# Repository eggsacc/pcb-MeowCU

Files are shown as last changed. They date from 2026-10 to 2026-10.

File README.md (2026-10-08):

<div align="center">

# MeowCU





4-layer **STM32F405RGT6 MeowCU** 🐱 (MCU) dev module with commonly used peripherals broken out for easy access, and a dedicated CAN transceiver. Also includes 2 user programmable buttons and mini OLED display.

>3D render - Front

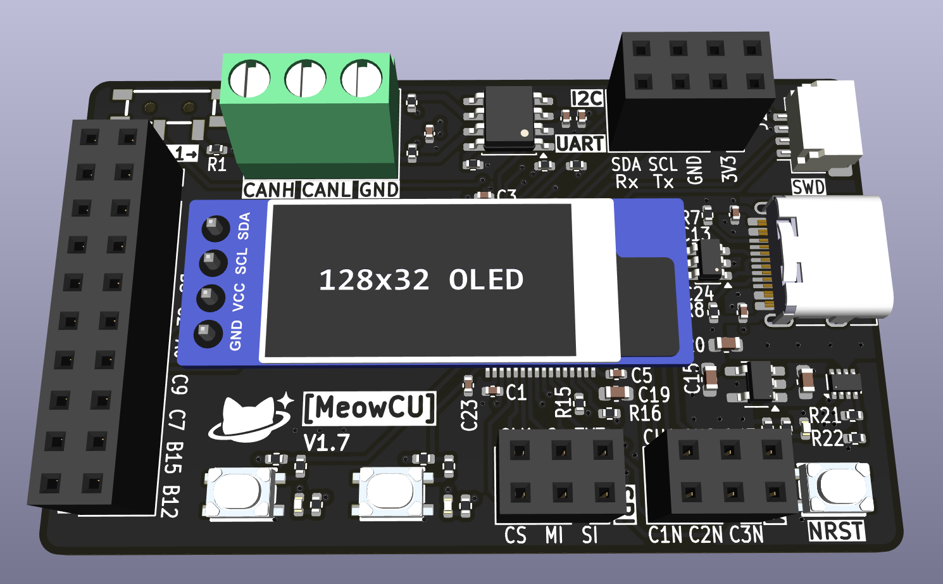
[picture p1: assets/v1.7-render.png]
STM32F4 dev module render


>Back

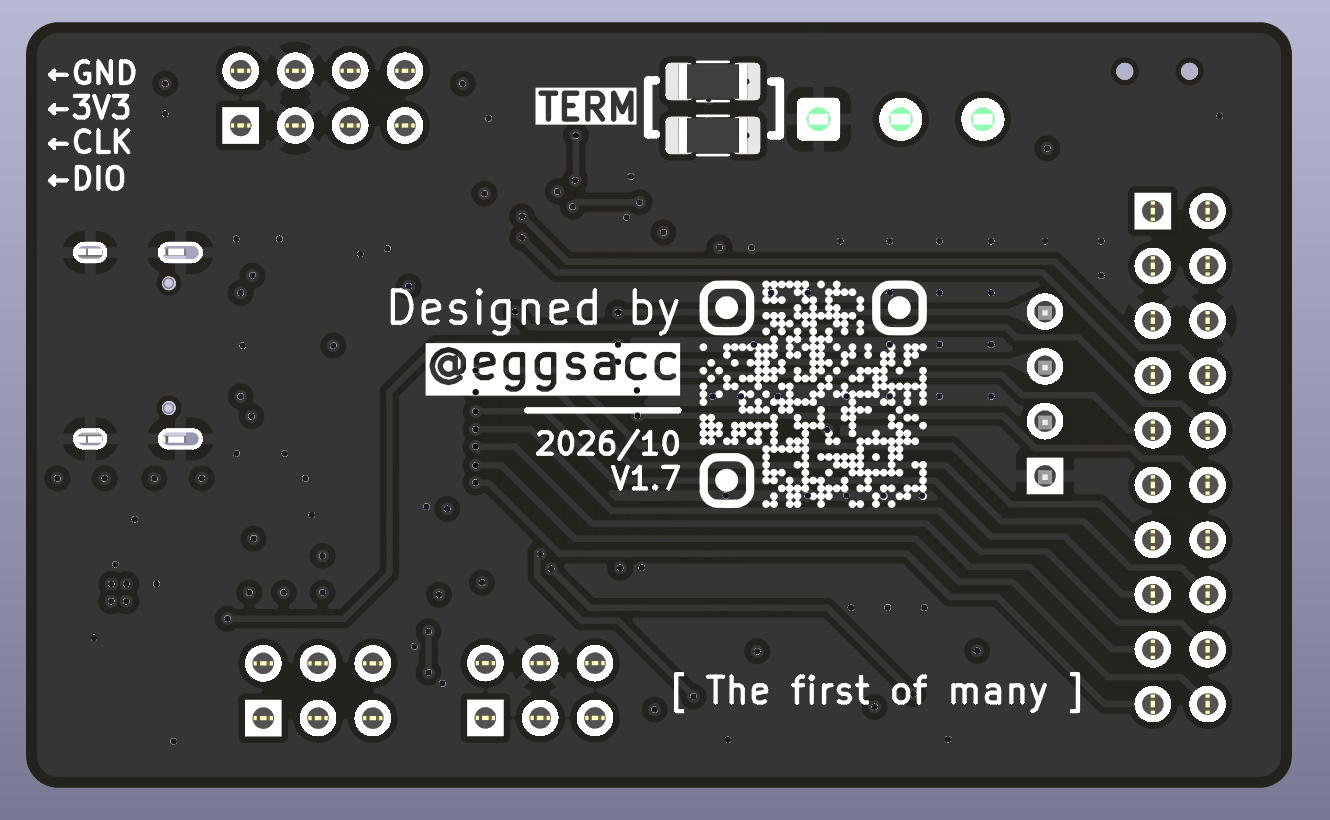
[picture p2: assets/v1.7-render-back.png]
STM32F4 dev module render


## Layout (all layers)
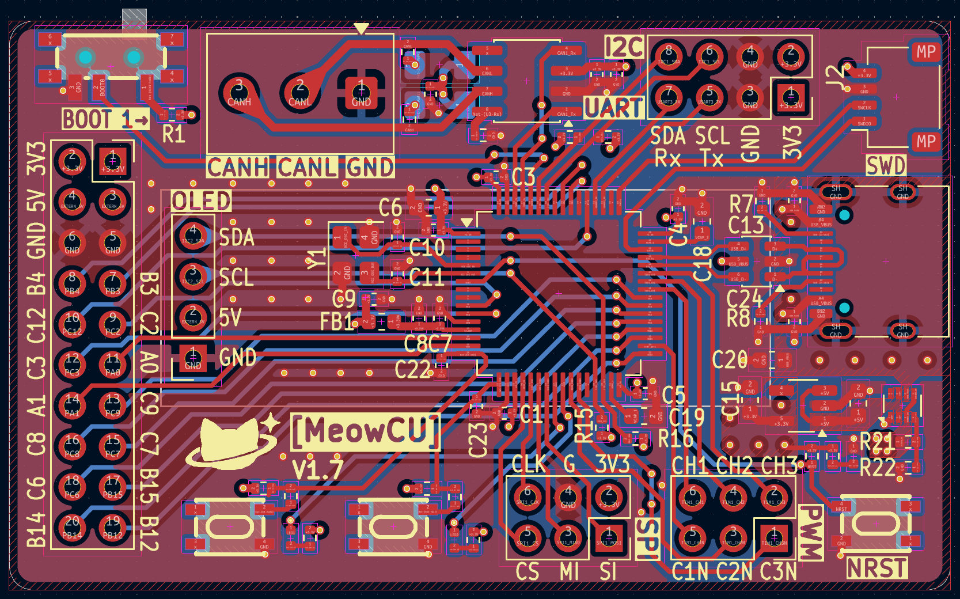
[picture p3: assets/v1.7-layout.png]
STM32CubeMX pin map

</div>

## MCU Pinout

<div align="center">
STM32CubeMX pin map

| Breakout / feature | Peripheral | Pin mapping |
|---|---|---|
| **UART header** | `USART3` | TX &rarr; `PC10`<br>RX &rarr; `PC11` |
| **SPI header** | `SPI1` | CS &rarr; `PA4`<br>SCK &rarr; `PA5`<br>MISO &rarr; `PA6`<br>MOSI &rarr; `PA7` |
| **I2C header** | `I2C1` | SCL &rarr; `PB6`<br>SDA &rarr; `PB7` |
| **CAN screw terminal** | `CAN1` (SN65HVD230) | TX &rarr; `PB9`<br>RX &rarr; `PB8` |
| **USB-C** | `USB_OTG_FS` | D&minus; &rarr; `PA11`<br>D+ &rarr; `PA12` |
| **SWD header** | `SYS` | SWDIO &rarr; `PA13`<br>SWCLK &rarr; `PA14` |
| **3-phase PWM header** | `TIM1` | <table><tbody><tr><td align="right">CH1 &rarr;</td><td><code>PA8</code></td><td align="right">&emsp;C1N &rarr;</td><td><code>PB13</code></td></tr><tr><td align="right">CH2 &rarr;</td><td><code>PA9</code></td><td align="right">&emsp;C2N &rarr;</td><td><code>PB0</code></td></tr><tr><td align="right">CH3 &rarr;</td><td><code>PA10</code></td><td align="right">&emsp;C3N &rarr;</td><td><code>PB1</code></td></tr></tbody></table> |
| **OLED** (on-board) | `I2C2` | SCL &rarr; `PB10`<br>SDA &rarr; `PB11` |
| **Utility buttons** (on-board) | `GPIO` / `EXTI` | L button &rarr; `PA2`<br>R button &rarr; `PA3` |
| **Crystal** (25MHz) | `RCC` HSE | OSC_IN &rarr; `PH0`<br>OSC_OUT &rarr; `PH1` |
| **GPIO header** (2&times;10) | free GPIO | <table><tbody><tr><td align="right">1 &rarr;</td><td><code>3.3V</code></td><td align="right">&emsp;2 &rarr;</td><td><code>3.3V</code></td></tr><tr><td align="right">3 &rarr;</td><td><code>5V</code></td><td align="right">&emsp;4 &rarr;</td><td><code>5V</code></td></tr><tr><td align="right">5 &rarr;</td><td><code>GND</code></td><td align="right">&emsp;6 &rarr;</td><td><code>GND</code></td></tr><tr><td align="right">7 &rarr;</td><td><code>PB4</code></td><td align="right">&emsp;8 &rarr;</td><td><code>PB3</code></td></tr><tr><td align="right">9 &rarr;</td><td><code>PC12</code></td><td align="right">&emsp;10 &rarr;</td><td><code>PC2</code></td></tr><tr><td align="right">11 &rarr;</td><td><code>PC3</code></td><td align="right">&emsp;12 &rarr;</td><td><code>PA0</code></td></tr><tr><td align="right">13 &rarr;</td><td><code>PA1</code></td><td align="right">&emsp;14 &rarr;</td><td><code>PC9</code></td></tr><tr><td align="right">15 &rarr;</td><td><code>PC8</code></td><td align="right">&emsp;16 &rarr;</td><td><code>PC7</code></td></tr><tr><td align="right">17 &rarr;</td><td><code>PC6</code></td><td align="right">&emsp;18 &rarr;</td><td><code>PB15</code></td></tr><tr><td align="right">19 &rarr;</td><td><code>PB14</code></td><td align="right">&emsp;20 &rarr;</td><td><code>PB12</code></td></tr></tbody></table> |

**Buttons are active-low to GND (3V3 pull-up).*
</div>

## Power mux

The external 5V pin and USB `vbus` are separate rails; a power mux IC (TPS2116) automatically switches to the external 5V rail when connected.

---

<div align="center">
Designed by <b>@eggsacc</b> · MeowCU V1.6<br>
Updated 09/10/2026
</div>

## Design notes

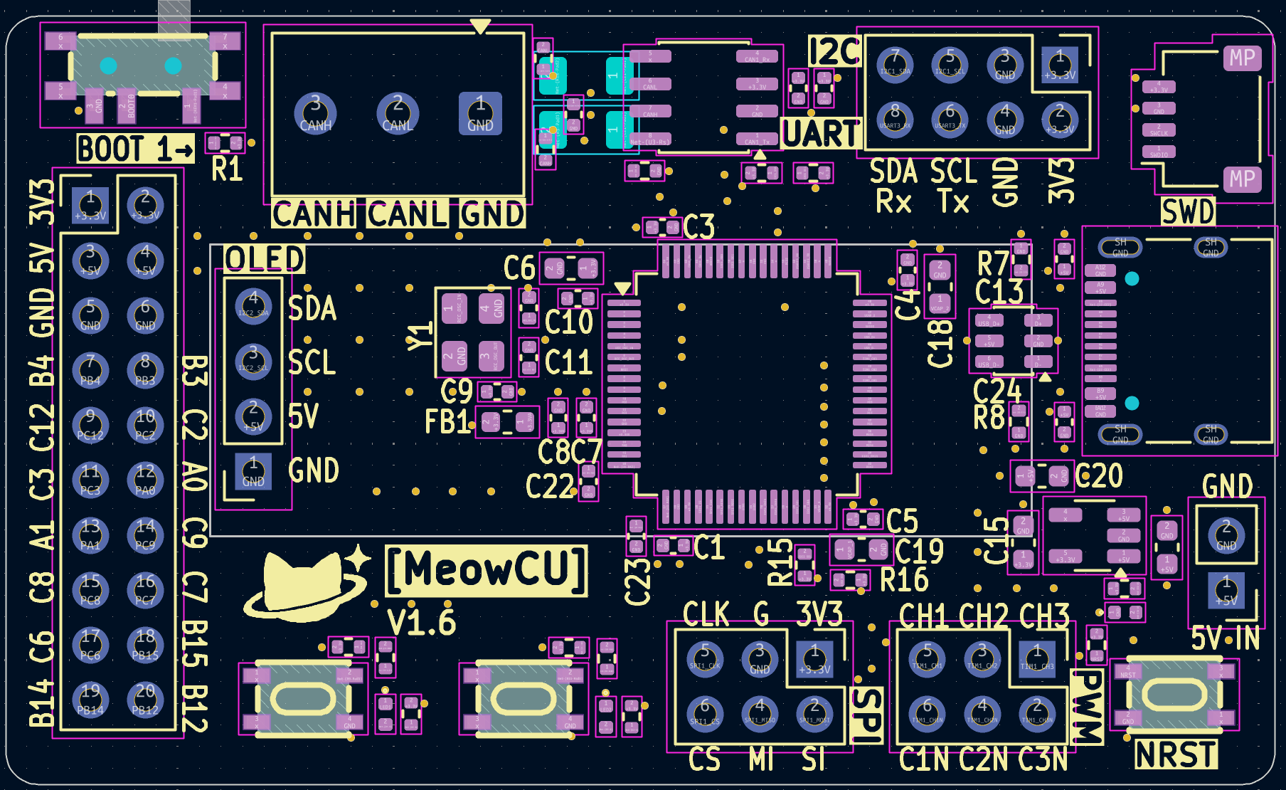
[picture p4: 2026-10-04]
assets/silkscreen-v1.6.png

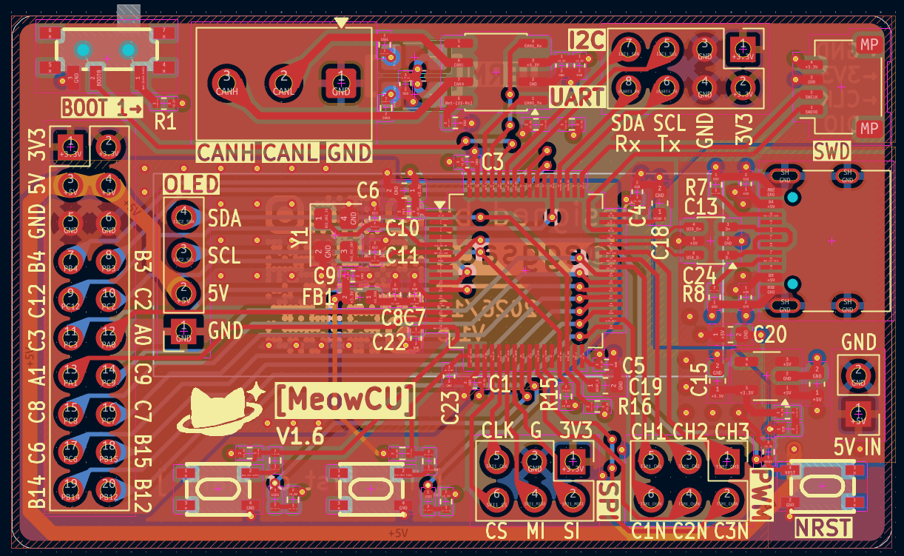
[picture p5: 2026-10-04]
assets/all-layers.png

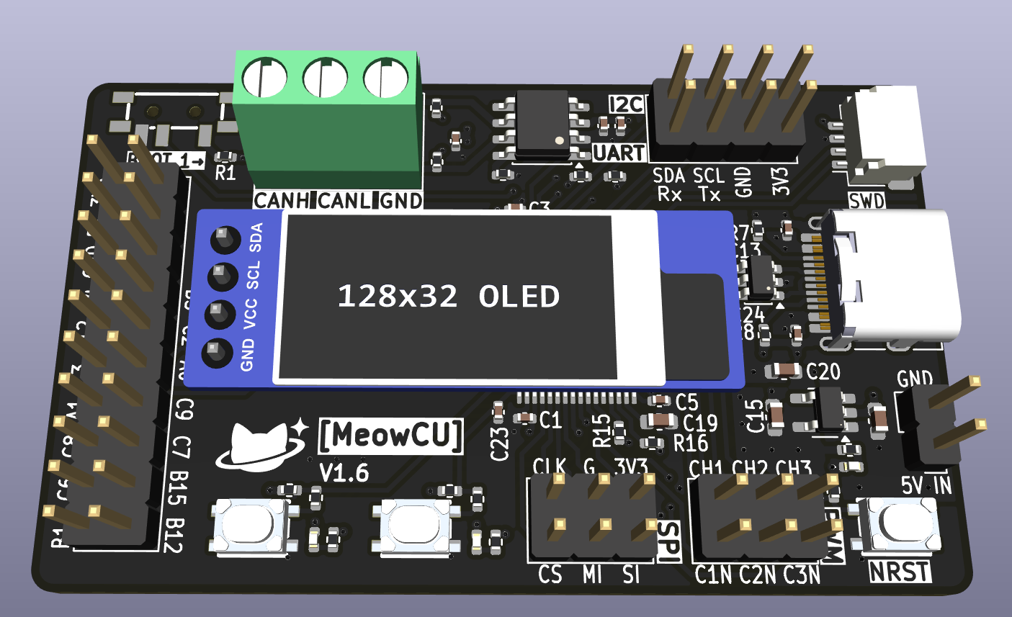
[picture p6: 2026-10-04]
assets/meowcu-v1.6-render.png

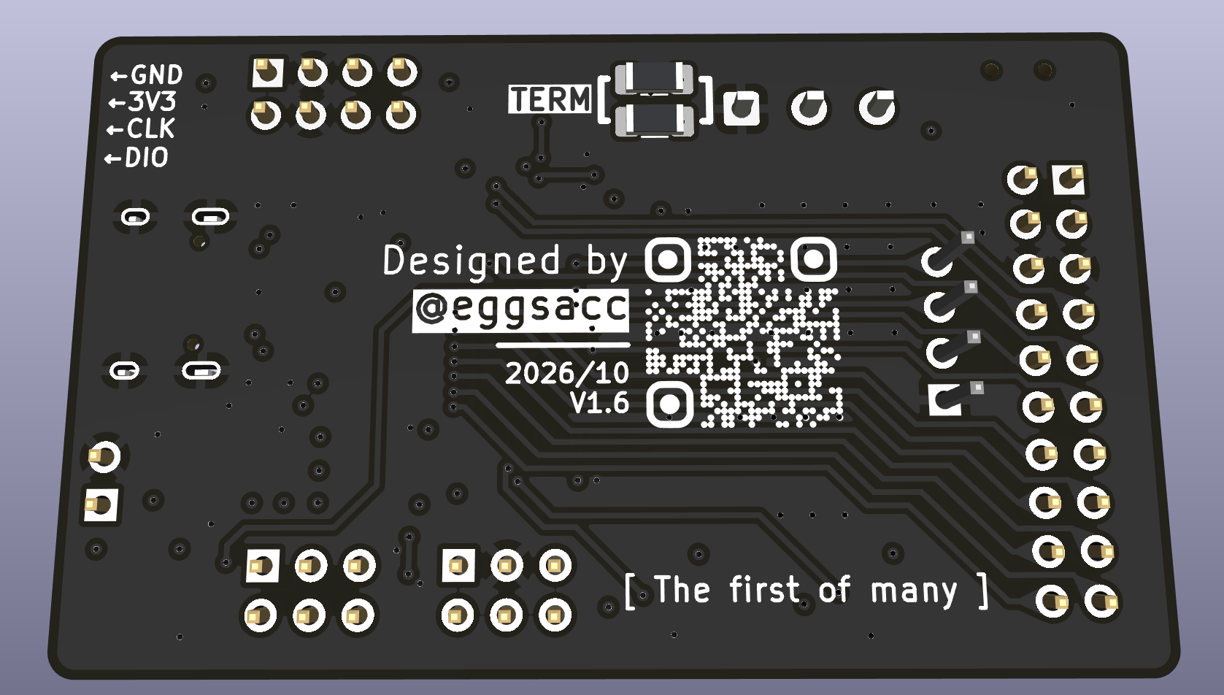
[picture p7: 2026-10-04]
assets/meowcu-v1.6-back-render.png

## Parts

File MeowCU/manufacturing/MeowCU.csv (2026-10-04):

Reference | Qty | Value | Footprint | Purhased | Qty | Link
C1,C2,C3,C4,C5,C13,C16,C22,C23,C24 | 10 | 100n | Capacitor_SMD:C_0402_1005Metric | TRUE | 100 | 0402??????? 22pF33pF47pF100pF2.2nF4.7nF100nF1uF10uF-???
C6 | 1 | 10u | Capacitor_SMD:C_0603_1608Metric | TRUE | 100 | 0603??????? 22pF33pF47pF100pF2.2nF4.7nF100nF1uF10uF-???
C7,C21 | 2 | 10n | Capacitor_SMD:C_0402_1005Metric | TRUE | 100 | 0402??????? 22pF33pF47pF100pF2.2nF4.7nF100nF1uF10uF-???
C8,C9,C17 | 3 | 1u | Capacitor_SMD:C_0402_1005Metric | TRUE | 100 | 0402??????? 22pF33pF47pF100pF2.2nF4.7nF100nF1uF10uF-???
C10,C11 | 2 | 14p | Capacitor_SMD:C_0402_1005Metric | TRUE | 100 | 0402??????? 22pF33pF47pF100pF2.2nF4.7nF100nF1uF10uF-???
C14,C15 | 2 | 1u | Capacitor_SMD:C_0603_1608Metric | TRUE | 100 | 0603??????? 22pF33pF47pF100pF2.2nF4.7nF100nF1uF10uF-???
C18,C19 | 2 | 2u2 | Capacitor_SMD:C_0603_1608Metric | TRUE | 100 | 0603??????? 22pF33pF47pF100pF2.2nF4.7nF100nF1uF10uF-???
C20 | 1 | 4u7 | Capacitor_SMD:C_0603_1608Metric | TRUE | 100 | 0603??????? 22pF33pF47pF100pF2.2nF4.7nF100nF1uF10uF-???
D1 | 1 | GREEN | LED_SMD:LED_0402_1005Metric | TRUE | 10 | ??LED 0402 0603 0805 1206??????? ?????????-tmall.com??
FB1 | 1 | 120R | Inductor_SMD:L_0603_1608Metric | TRUE | 100 | 0603?????????30R60R100R120R150R220R300R600R1K2K2.5K-???
J1 | 1 | SW | Connector_JST:JST_SH_SM04B-SRSS-TB_1x04-1MP_P1.00mm_Horizontal | TRUE | 10 | ???SH1.0??JSTSH ???1.0mm????/??/???????-???
J3 | 1 | I2C1 | Connector_PinHeader_2.54mm:PinHeader_1x04_P2.54mm_Vertical | TRUE | 0
J4 | 1 | SPI1 | Connector_PinHeader_2.54mm:PinHeader_2x03_P2.54mm_Vertical | TRUE | 0 | ?/??? ??2.54MM 1*2p/3p/4p/8P/16p/20p?? LCD1602/12864-tmall.com??
J5 | 1 | 5V_IN | Connector_PinHeader_2.54mm:PinHeader_1x02_P2.54mm_Vertical | TRUE | 0
J6 | 1 | OLED | addons:OLED header | TRUE | 0
J7 | 1 | USB_C_Receptacle_USB2.0_16P | Connector_USB:USB_C_Receptacle_G-Switch_GT-USB-7010ASV | TRUE | 0 | USB Type-C 16P?????????????????USB???-???
J8 | 1 | USART3 | Connector_PinHeader_2.54mm:PinHeader_1x04_P2.54mm_Vertical | TRUE | 0
J9 | 1 | PWM | Connector_PinHeader_2.54mm:PinHeader_2x03_P2.54mm_Vertical | TRUE | 0
J10 | 1 | Screw_Terminal_01x03 | TerminalBlock_Phoenix:TerminalBlock_Phoenix_MKDS-1-3-3.81_1x03_P3.81mm_Horizontal | TRUE | 0 | KF128/126????2P???2.54/3.81/5.08MM??5.0?????3P-tmall.com??
J11 | 1 | Conn_02x10_Odd_Even | Connector_PinHeader_2.54mm:PinHeader_2x10_P2.54mm_Vertical | TRUE | 0
R1,R3,R10,R12 | 4 | 10k | Resistor_SMD:R_0402_1005Metric | TRUE | 0 | 0402?????? ??1% 10R1K1.2K2.2K3.3K4.7K5.1K10K100K1M?-???
R2 | 1 | 330 | Resistor_SMD:R_0402_1005Metric | TRUE | 0 | 0402?????? ??1% 10R1K1.2K2.2K3.3K4.7K5.1K10K100K1M?-???
R4,R5 | 2 | 60 | Resistor_SMD:R_0402_1005Metric | TRUE | 0 | 0402?????? ??1% 10R1K1.2K2.2K3.3K4.7K5.1K10K100K1M?-???
R6 | 1 | 0 | Resistor_SMD:R_0603_1608Metric | TRUE | 0 | 0402 0603 0805 1206????1%5% 1R10R100R1K 4.7K10K 47K 100K-???
R7,R8 | 2 | 5k1 | Resistor_SMD:R_0402_1005Metric | TRUE | 0 | 0402?????? ??1% 10R1K1.2K2.2K3.3K4.7K5.1K10K100K1M?-???
R9,R11 | 2 | 100 | Resistor_SMD:R_0402_1005Metric | TRUE | 0 | 0402?????? ??1% 10R1K1.2K2.2K3.3K4.7K5.1K10K100K1M?-???
SW1 | 1 | SW_SPST | Button_Switch_SMD:SW_DIP_SPSTx01_Slide_6.7x4.1mm_W6.73mm_P2.54mm_LowProfile_JPin | TRUE | 10 | ??????/??1/2/3/4/5/6/7/8/9/10/12p??1.27/2.54mm??-???
SW5,SW6 | 2 | BTN_UTIL | addons:SW-SMD_4P-L4.2-W3.4-P2.15-LS5.2 | TRUE | 0 | ????4???2??????????????????????-tmall.com??
SW7 | 1 | BTN | addons:SW-SMD_4P-L4.2-W3.4-P2.15-LS5.2 | TRUE | 40 | ????4???2??????????????????????-tmall.com??
U1 | 1 | STM32F405RGT6 | Package_QFP:LQFP-64_10x10mm_P0.5mm | TRUE | 2 | ???? STM32F405RGT6 STM32F405VGT6 405ZGT6 405OEY6TR VGT7-tmall.com??
U2 | 1 | USBLC6-2SC6 | Package_TO_SOT_SMD:SOT-23-6 | TRUE | 20 | USBLC6-2SC6 USB2.0??ESD????? ???? ??UL26 SOT-23-tmall.com??
U3 | 1 | SN65HVD230 | Package_SO:SOIC-8_3.9x4.9mm_P1.27mm | TRUE | 5 | ???? ?? SN65HVD230DR SOP-8 CAN????? ??-???
U4 | 1 | AP2112K-3.3 | Package_TO_SOT_SMD:SOT-23-5_HandSoldering | TRUE | 10 | AP2112K-3.3TRG1 1.2V 1.8V 2.5V ??G3M LDO????? SOT23-5-???
Y1 | 1 | 25MHz | Crystal:Crystal_SMD_3225-4Pin_3.2x2.5mm | TRUE | 10 | 3225_4P???????? 8/12/13.56/16/20/24/25/26/32/40MHz-???
 |  |  | Request from seller values
 | ??
 | 1 | 100nF, 16V, X7R | 0402
 | 2 | 10nF, 50V, X7R | 0402
 | 3 | 1uF, 25V, X5R, 10% | 0402
 | 4 | 13pF, 50V, C0G | 0402
 | 5 | 1uF, 16V, X7R, 10% | 0603
 | 6 | 2.2uF, 16V, X7R, 10% | 0603
 | 7 | 4.7uF, 16V, X5R, 10% | 0603
 | 8 | 10uF, 10V, X5R, 10% | 0603
 | ??
 | 1 | 10k | 0402
 | 2 | 330 | 0402
 | 3 | 60 | 0402
 | 4 | 5.1K | 0402
 | 5 | 100 | 0403
 | 6 | 0 | 0603

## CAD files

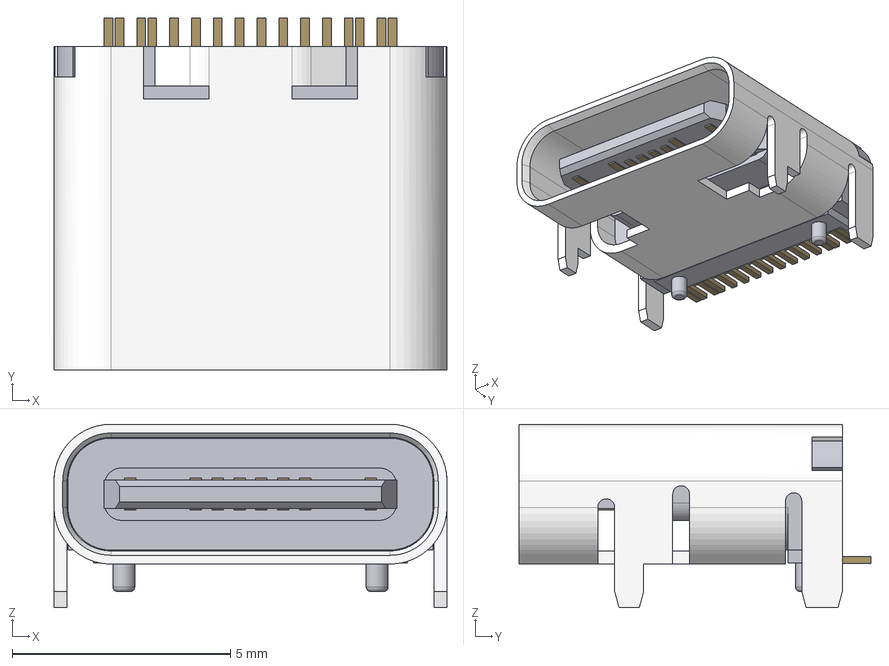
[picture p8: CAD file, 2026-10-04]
MeowCU/3d-models/usb-c_16pins_vertical.step
9.00 x 8.05 x 4.20 mm
tongue
shield
contact_001
contact_002
contact_003
contact_004
contact_court_001
contact_court_002
contact_court_003
contact_court_004
contact_005
contact_006
contact_007
contact_008
contact_court_005
contact_court_006
contact_court_007
contact_court_008
pin_001
pin_002
pin_003
pin_004
pin_005
pin_006
pin_007
pin_008
pin_009
pin_010
pin_011
pin_012
pin_013
pin_014
pin_015
pin_016

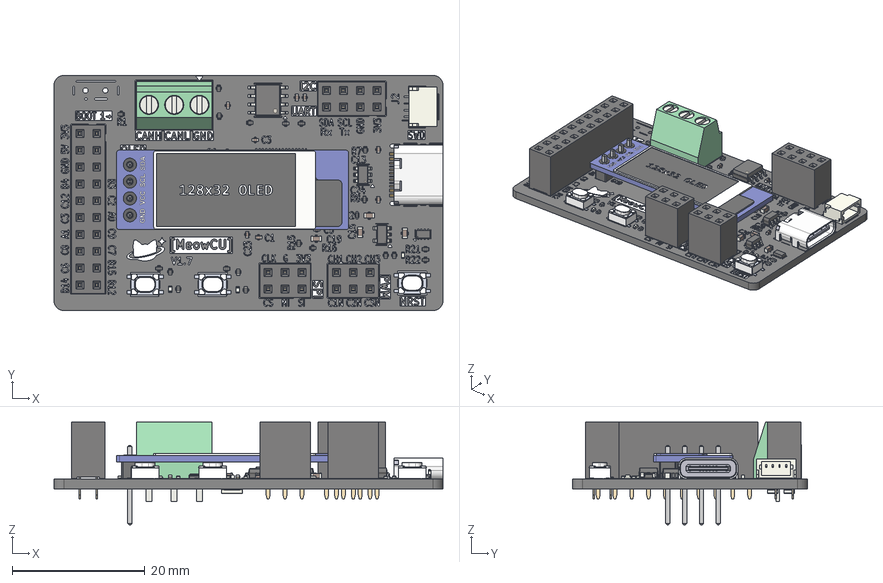
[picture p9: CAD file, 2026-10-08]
MeowCU/MeowCU.step
58.7 x 35.5 x 15.5 mm
C_0402_1005Metric x 17
R_0402_1005Metric x 20
SOT-23-5
LED_0402_1005Metric x 3
C_0603_1608Metric x 6
L_0603_1608Metric
JST_SH_SM04B-SRSS-TB_1x04-1MP_P1.00mm_Horizontal
PinSocket_2x03_P2.54mm_Vertical x 2
Crystal_SMD_3225-4Pin_3.2x2.5mm
PinSocket_2x04_P2.54mm_Vertical
TerminalBlock_Phoenix_MKDS-1-3-3.81_1x03_P3.81mm_Horizontal
sw3x4 x 3
sw3x4_cap x 3
sw3x4_cover x 3
sw3x4_hold x 3
sw3x4_pin x 6
¾µвsw3x4_hold x 6
¾µв¾µвsw3x4_hold x 3
SOT-23-6
PinSocket_2x10_P2.54mm_Vertical
SOIC-8_3.9x4.9mm_P1.27mm
SOT-583-8
tongue
shield
contact_001
contact_002
contact_003
contact_004
contact_court_001
contact_court_002
contact_court_003
contact_court_004
contact_005
contact_006
contact_007
contact_008
contact_court_005
contact_court_006
contact_court_007
contact_court_008
pin_001
pin_002
pin_003
pin_004
pin_005
pin_006
pin_007
pin_008
pin_009
pin_010
pin_011
pin_012
pin_013
pin_014
pin_015
pin_016
LQFP-64_10x10mm_P0.5mm
R_1206_3216Metric x 2
MeowCU_silkscreen x 2
MeowCU_PCB

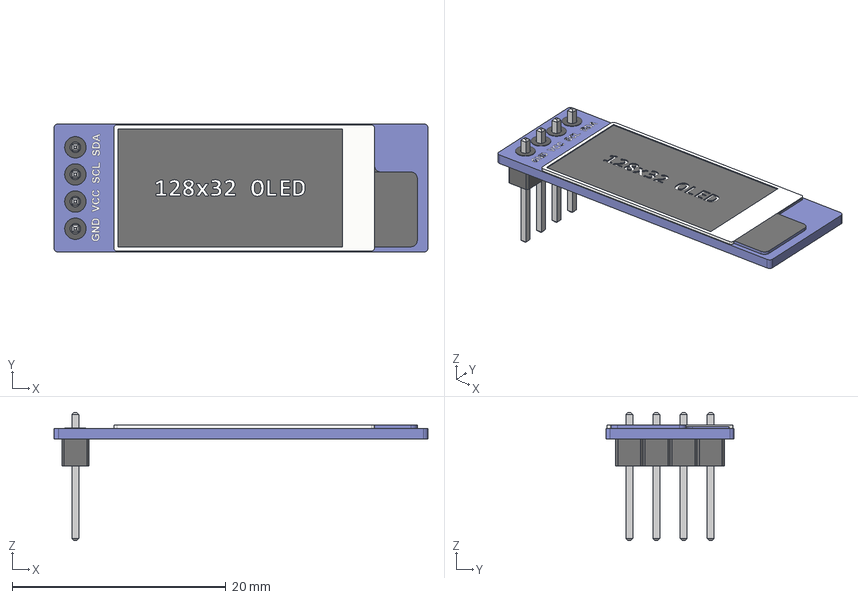
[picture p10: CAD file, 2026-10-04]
MeowCU/3d-models/128x32 OLED.step
35.0 x 12.0 x 12.0 mm

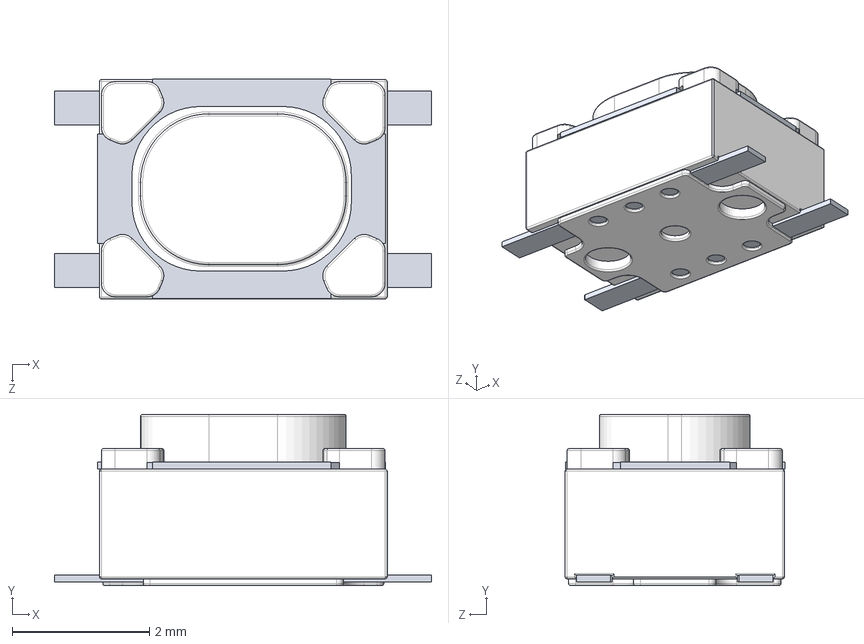
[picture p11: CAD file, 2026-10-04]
MeowCU/3d-models/SW3x4.STEP
5.50 x 2.50 x 3.21 mm
sw3x4
sw3x4_cap
sw3x4_cover
sw3x4_hold
sw3x4_pin x 2
噩砃sw3x4_hold x 2
镜向镜向sw3x4_hold

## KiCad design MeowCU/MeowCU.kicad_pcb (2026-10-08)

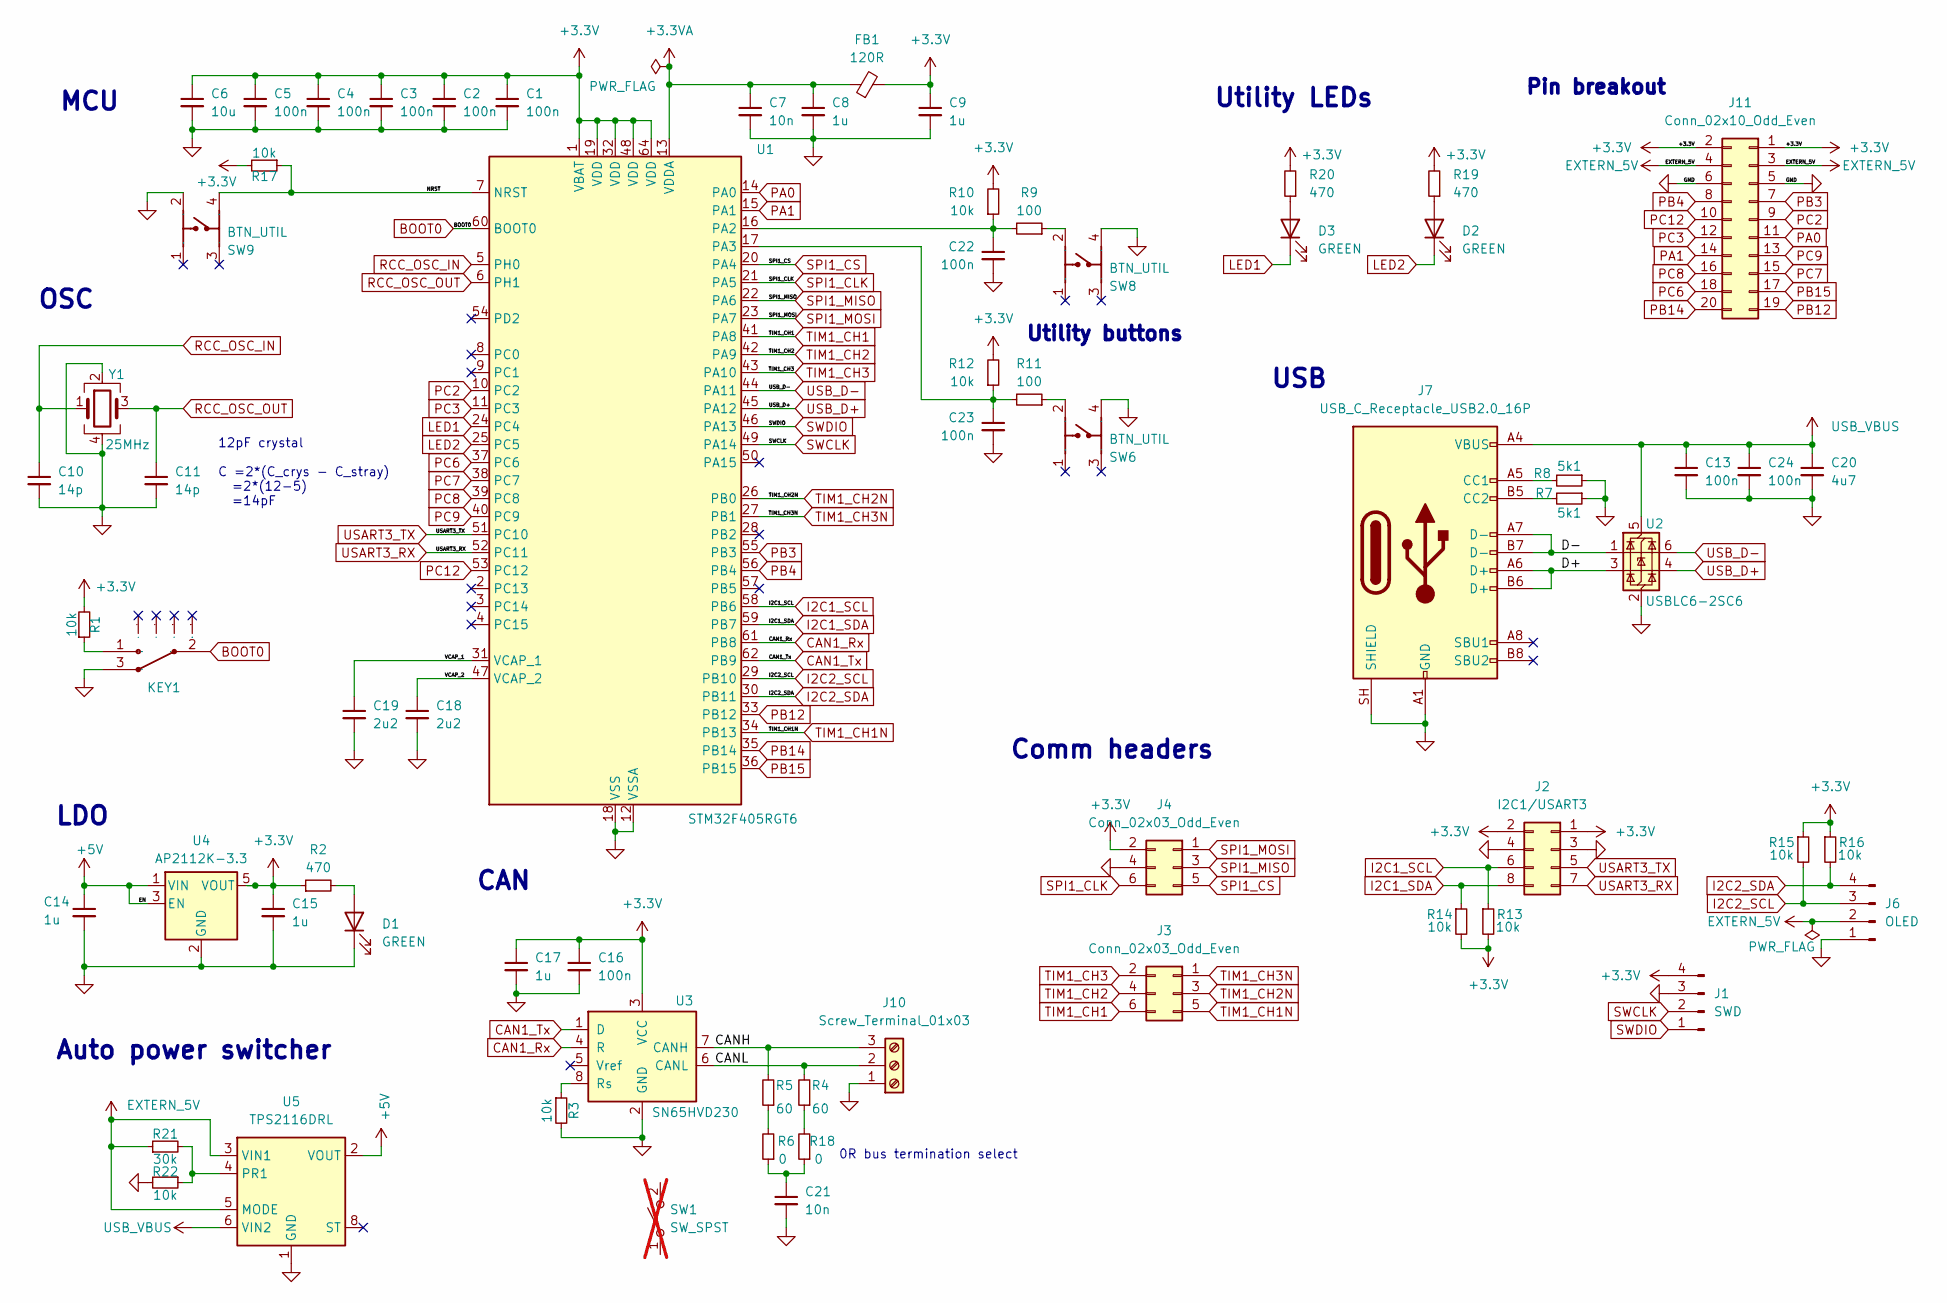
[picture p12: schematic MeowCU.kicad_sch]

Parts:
C1, C2, C3, C4, C5, C13, C16, C22, C23, C24: 100n; C_0402_1005Metric
C6: 10u; C_0603_1608Metric
C7, C21: 10n; C_0402_1005Metric
C8, C9, C17: 1u; C_0402_1005Metric
C10, C11: 14p; C_0402_1005Metric
C14, C15: 1u; C_0603_1608Metric
C18, C19: 2u2; C_0603_1608Metric
C20: 4u7; C_0603_1608Metric
D1, D2, D3: GREEN; LED_0402_1005Metric
FB1: 120R; L_0603_1608Metric
J1: SWD; JST_SH_SM04B-SRSS-TB_1x04-1MP_P1.00mm_Horizontal
J2: I2C1/USART3; PinSocket_2x04_P2.54mm_Vertical
J3, J4: Conn_02x03_Odd_Even; PinSocket_2x03_P2.54mm_Vertical
J6: OLED; OLED header
J7: USB_C_Receptacle_USB2.0_16P; USB_C_Receptacle_HRO_TYPE-C-31-M-12
J10: Screw_Terminal_01x03; TerminalBlock_Phoenix_MKDS-1-3-3.81_1x03_P3.81mm_Horizontal
J11: Conn_02x10_Odd_Even; PinSocket_2x10_P2.54mm_Vertical
KEY1: MSK-11027 Toggle Switches; SW-SMD_MSK-11027; Manufacturer Part MSK-11027 Toggle Switches
R1, R3, R10, R12, R13, R14, R15, R16, R17, R22: 10k; R_0402_1005Metric
R2, R19, R20: 470; R_0402_1005Metric
R4, R5: 60; R_0402_1005Metric
R6, R18: 0; R_1206_3216Metric_Pad1.30x1.75mm_HandSolder
R7, R8: 5k1; R_0402_1005Metric
R9, R11: 100; R_0402_1005Metric
R21: 30k; R_0402_1005Metric
SW1: SW_SPST; SW_DIP_SPSTx01_Slide_Copal_CHS-01A_W5.08mm_P1.27mm_JPin; not fitted
SW6, SW8, SW9: BTN_UTIL; SW-SMD_4P-L4.2-W3.4-P2.15-LS5.2; Manufacturer Part HX 3x4x2.5-PA-4N push button switch
U1: STM32F405RGT6; LQFP-64_10x10mm_P0.5mm
U2: USBLC6-2SC6; SOT-23-6
U3: SN65HVD230; SOIC-8_3.9x4.9mm_P1.27mm
U4: AP2112K-3.3; SOT-23-5_HandSoldering
U5: TPS2116DRL; SOT-583-8
Y1: 25MHz; Crystal_SMD_3225-4Pin_3.2x2.5mm

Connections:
+3.3V: C1.1, C2.1, C3.1, C4.1, C5.1, C6.1, C9.1, C15.1, C16.1, C17.1, FB1.2, J1.4, J2.1, J2.2, J4.2, J11.1, J11.2, R1.2, R2.1, R10.2, R12.2, R13.2, R14.2, R15.1, R16.1, R17.2, R19.2, R20.2, U1.1 (VBAT), U1.19 (VDD), U1.32 (VDD), U1.48 (VDD), U1.64 (VDD), U3.3 (VCC), U4.5 (VOUT)
+3.3VA: C7.1, C8.1, FB1.1, U1.13 (VDDA)
+5V: C14.1, U4.1 (VIN), U4.3 (EN), U5.2 (VOUT), U5.7 (VOUT)
/CANH: J10.3, R5.2, U3.7 (CANH)
/CANL: J10.2, R4.2, U3.6 (CANL)
/D+: J7.A6 (D+), J7.B6 (D+), U2.3 (I/O2)
/D-: J7.A7 (D-), J7.B7 (D-), U2.1 (I/O1)
/NRST: R17.1, SW9.4, U1.7 (NRST)
/VCAP_1: C19.1, U1.31 (VCAP_1)
/VCAP_2: C18.1, U1.47 (VCAP_2)
BOOT0: KEY1.2, U1.60 (BOOT0)
CAN1_Rx: U1.61 (PB8), U3.4 (R)
CAN1_Tx: U1.62 (PB9), U3.1 (D)
EXTERN_5V: J6.2, J11.3, J11.4, R21.1, U5.3 (VIN1), U5.5 (MODE)
GND: C1.2, C2.2, C3.2, C4.2, C5.2, C6.2, C7.2, C8.2, C9.2, C10.2, C11.2, C13.2, C14.2, C15.2, C16.2, C17.2, C18.2, C19.2, C20.2, C21.2, C22.2, C23.2, C24.2, D1.1 (K), J1.3, J2.3, J2.4, J4.4, J6.1, J7.A1 (GND), J7.A12 (GND), J7.B1 (GND), J7.B12 (GND), J7.SH (SHIELD), J10.1, J11.5, J11.6, KEY1.3, R3.2, R7.1, R8.1, R22.2, SW6.4, SW8.4, SW9.2, U1.12 (VSSA), U1.18 (VSS), U1.63 (VSS), U2.2 (GND), U3.2 (GND), U4.2 (GND), U5.1 (GND), Y1.2, Y1.4
I2C1_SCL: J2.6, R13.1, U1.58 (PB6)
I2C1_SDA: J2.8, R14.1, U1.59 (PB7)
I2C2_SCL: J6.3, R15.2, U1.29 (PB10)
I2C2_SDA: J6.4, R16.2, U1.30 (PB11)
LED1: D3.1 (K), U1.24 (PC4)
LED2: D2.1 (K), U1.25 (PC5)
unnamed: C21.1, R6.1, R18.1
unnamed: D1.2 (A), R2.2
unnamed: D2.2 (A), R19.1
unnamed: D3.2 (A), R20.1
unnamed: J7.A5 (CC1), R8.2
unnamed: J7.B5 (CC2), R7.2
unnamed: KEY1.1, R1.1
unnamed: R5.1, R6.2
unnamed: R9.1, SW8.2
unnamed: R11.1, SW6.2
unnamed: R4.1, R18.2
unnamed: C22.1, R9.2, R10.1, U1.16 (PA2)
unnamed: C23.1, R11.2, R12.1, U1.17 (PA3)
unnamed: R3.1, U3.8 (Rs)
unnamed: R21.2, R22.1, U5.4 (PR1)
PA0: J11.11, U1.14 (PA0)
PA1: J11.14, U1.15 (PA1)
PB3: J11.7, U1.55 (PB3)
PB4: J11.8, U1.56 (PB4)
PB12: J11.19, U1.33 (PB12)
PB14: J11.20, U1.35 (PB14)
PB15: J11.17, U1.36 (PB15)
PC2: J11.9, U1.10 (PC2)
PC3: J11.12, U1.11 (PC3)
PC6: J11.18, U1.37 (PC6)
PC7: J11.15, U1.38 (PC7)
PC8: J11.16, U1.39 (PC8)
PC9: J11.13, U1.40 (PC9)
PC12: J11.10, U1.53 (PC12)
RCC_OSC_IN: C10.1, U1.5 (PH0), Y1.1
RCC_OSC_OUT: C11.1, U1.6 (PH1), Y1.3
SPI1_CLK: J4.6, U1.21 (PA5)
SPI1_CS: J4.5, U1.20 (PA4)
SPI1_MISO: J4.3, U1.22 (PA6)
SPI1_MOSI: J4.1, U1.23 (PA7)
SWCLK: J1.2, U1.49 (PA14)
SWDIO: J1.1, U1.46 (PA13)
TIM1_CH1: J3.6, U1.41 (PA8)
TIM1_CH1N: J3.5, U1.34 (PB13)
TIM1_CH2: J3.4, U1.42 (PA9)
TIM1_CH2N: J3.3, U1.26 (PB0)
TIM1_CH3: J3.2, U1.43 (PA10)
TIM1_CH3N: J3.1, U1.27 (PB1)
USART3_RX: J2.7, U1.52 (PC11)
USART3_TX: J2.5, U1.51 (PC10)
USB_D+: U1.45 (PA12), U2.4 (I/O2)
USB_D-: U1.44 (PA11), U2.6 (I/O1)
USB_VBUS: C13.1, C20.1, C24.1, J7.A4 (VBUS), J7.A9 (VBUS), J7.B4 (VBUS), J7.B9 (VBUS), U2.5 (VBUS), U5.6 (VIN2)

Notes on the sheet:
Auto power switcher
MCU
Pin breakout
Comm headers
CAN
Utility LEDs
12pF crystal C =2*(C_crys - C_stray) =2*(12-5) =14pF
USB
Utility buttons
LDO
OSC
0R bus termination select

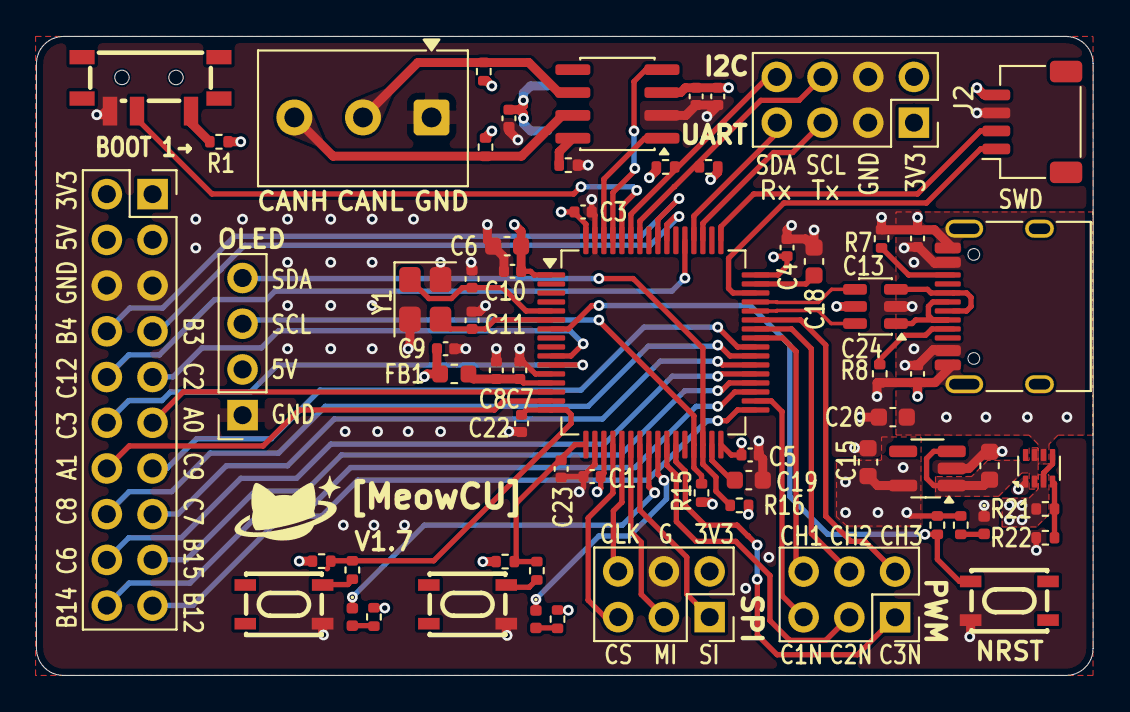
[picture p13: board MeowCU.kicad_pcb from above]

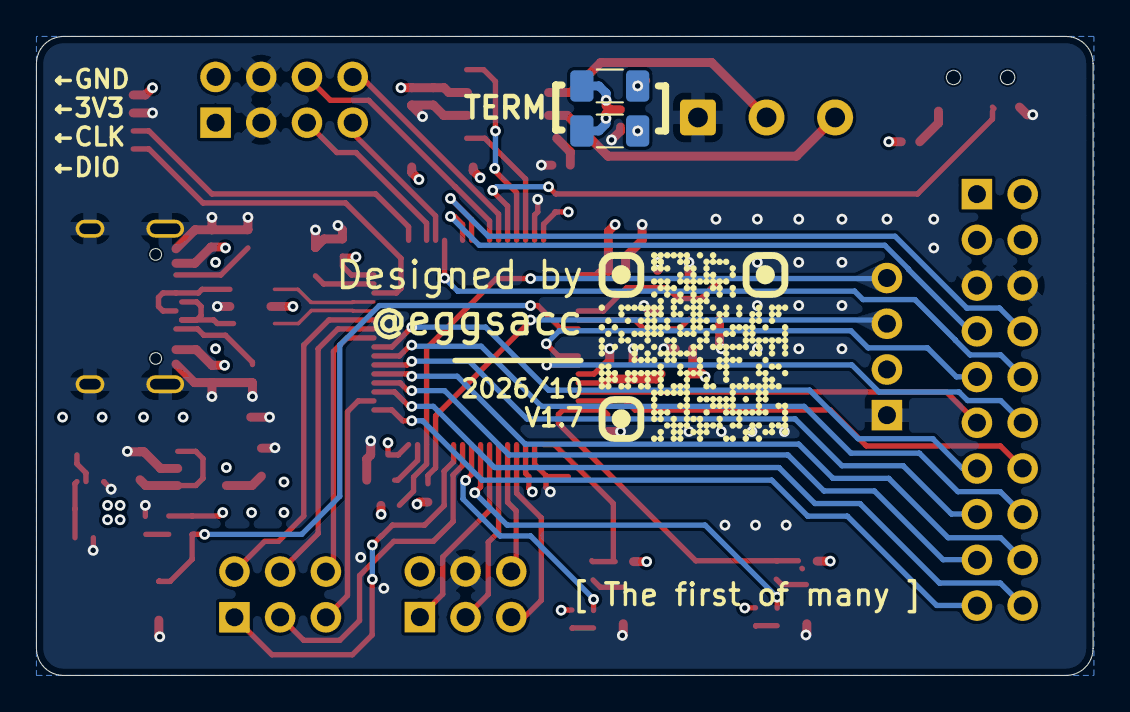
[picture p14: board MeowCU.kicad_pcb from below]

Board: 4 copper layers, 58.7 x 35.5 mm, 67 parts (2 on the bottom side), 69 nets.

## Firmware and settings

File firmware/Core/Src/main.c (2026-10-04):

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
/* Includes ------------------------------------------------------------------*/
#include "main.h"
#include "usb_device.h"

/* USER CODE BEGIN Includes */
#include "usbd_cdc_if.h"
#include "ssd1306.h"
/* USER CODE END Includes */

ADC_HandleTypeDef hadc1;

CAN_HandleTypeDef hcan1;

I2C_HandleTypeDef hi2c1;
I2C_HandleTypeDef hi2c2;

SPI_HandleTypeDef hspi1;

TIM_HandleTypeDef htim1;

UART_HandleTypeDef huart3;

void SystemClock_Config(void);
static void MX_GPIO_Init(void);
static void MX_CAN1_Init(void);
static void MX_I2C1_Init(void);
static void MX_SPI1_Init(void);
static void MX_USART3_UART_Init(void);
static void MX_I2C2_Init(void);
static void MX_TIM1_Init(void);
static void MX_ADC1_Init(void);
/* USER CODE BEGIN 0 */
/*
 * Workaround for STM32F4 errata ES0182 "I2C analog filter may provide wrong value,
 * locking BUSY flag and preventing master mode entry". Manually toggles SCL/SDA as
 * GPIO, then resets the peripheral and re-initialises it.
 * Returns 0 on success, or the step number that failed (line did not follow).
 */
static int I2C_BusRecover(I2C_HandleTypeDef *hi2c, GPIO_TypeDef *port, uint16_t scl, uint16_t sda)
{
  GPIO_InitTypeDef gpio = {0};

  __HAL_I2C_DISABLE(hi2c);

  /* Take the pins over as open-drain GPIO, released high */
  HAL_GPIO_WritePin(port, scl | sda, GPIO_PIN_SET);
  gpio.Pin = scl | sda;
  gpio.Mode = GPIO_MODE_OUTPUT_OD;
  gpio.Pull = GPIO_NOPULL;
  gpio.Speed = GPIO_SPEED_FREQ_VERY_HIGH;
  HAL_GPIO_Init(port, &gpio);
  HAL_Delay(1);
  if (HAL_GPIO_ReadPin(port, scl) != GPIO_PIN_SET || HAL_GPIO_ReadPin(port, sda) != GPIO_PIN_SET)
    return 1; /* something external is holding a line low */

  /* Clock out up to 9 pulses in case a slave is stuck mid-byte holding SDA */
  for (int i = 0; i < 9; i++)
  {
    HAL_GPIO_WritePin(port, scl, GPIO_PIN_RESET);
    HAL_Delay(1);
    HAL_GPIO_WritePin(port, scl, GPIO_PIN_SET);
    HAL_Delay(1);
  }

  /* Generate a STOP by hand: SDA low, SCL low, SCL high, SDA high */
  HAL_GPIO_WritePin(port, sda, GPIO_PIN_RESET);
  HAL_Delay(1);
  if (HAL_GPIO_ReadPin(port, sda) != GPIO_PIN_RESET) return 2;
  HAL_GPIO_WritePin(port, scl, GPIO_PIN_RESET);
  HAL_Delay(1);
  if (HAL_GPIO_ReadPin(port, scl) != GPIO_PIN_RESET) return 3;
  HAL_GPIO_WritePin(port, scl, GPIO_PIN_SET);
  HAL_Delay(1);
  if (HAL_GPIO_ReadPin(port, scl) != GPIO_PIN_SET) return 4;
  HAL_GPIO_WritePin(port, sda, GPIO_PIN_SET);
  HAL_Delay(1);
  if (HAL_GPIO_ReadPin(port, sda) != GPIO_PIN_SET) return 5;

  /* Hand the pins back to the I2C peripheral; HAL_I2C_Init does the SWRST pulse */
  HAL_I2C_DeInit(hi2c);
  if (HAL_I2C_Init(hi2c) != HAL_OK) return 6;
  return 0;
}
/* USER CODE END 0 */

/**
  * @brief  The application entry point.
  * @retval int
  */
int main(void)
{

  /* MCU Configuration--------------------------------------------------------*/

  /* Reset of all peripherals, Initializes the Flash interface and the Systick. */
  HAL_Init();

  /* Configure the system clock */
  SystemClock_Config();

  /* Initialize all configured peripherals */
  MX_GPIO_Init();
  MX_CAN1_Init();
  MX_I2C1_Init();
  MX_SPI1_Init();
  MX_USART3_UART_Init();
  MX_I2C2_Init();
  MX_TIM1_Init();
  MX_ADC1_Init();
  MX_USB_DEVICE_Init();
  /* USER CODE BEGIN 2 */
  int rec = I2C_BusRecover(&hi2c2, GPIOB, I2C2_SCL_Pin, I2C2_SDA_Pin);
  HAL_StatusTypeDef st = HAL_I2C_IsDeviceReady(&hi2c2, 0x3C << 1, 3, 100);
  (void)rec;
  if (st == HAL_OK)
  {
    ssd1306_Init();
    ssd1306_Fill(White);
    ssd1306_UpdateScreen();
  }
  /* USER CODE END 2 */

  /* Infinite loop */
  /* USER CODE BEGIN WHILE */
  while (1)
  {
    CDC_Transmit_FS((uint8_t *)"Hello World!\n", 13);
    HAL_Delay(1000);
    /* USER CODE END WHILE */

    /* USER CODE BEGIN 3 */
  }
  /* USER CODE END 3 */
}

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


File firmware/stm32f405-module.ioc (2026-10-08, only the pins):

Mcu.UserName=STM32F405RGTx
PA0-WKUP.GPIO_Label=SOA
PA0-WKUP.Signal=ADCx_IN0
PA1.GPIO_Label=VIN_SENSE
PA1.Signal=ADCx_IN1
PA10.Signal=S_TIM1_CH3
PA11.Signal=USB_OTG_FS_DM
PA12.Signal=USB_OTG_FS_DP
PA13.Signal=SYS_JTMS-SWDIO
PA14.Signal=SYS_JTCK-SWCLK
PA2.GPIO_Label=GPIO_EXTI2(Push1)
PA2.Signal=GPXTI2
PA3.GPIO_Label=GPIO_EXTI3(Push2)
PA3.Signal=GPXTI3
PA4.GPIO_Label=SPI1_CS
PA4.Signal=GPIO_Output
PA5.Signal=SPI1_SCK
PA6.Signal=SPI1_MISO
PA7.Signal=SPI1_MOSI
PA8.Signal=S_TIM1_CH1
PA9.Signal=S_TIM1_CH2
PB0.Signal=TIM1_CH2N
PB1.Signal=TIM1_CH3N
PB10.GPIO_Label=I2C2_SCL(OLED)
PB10.Signal=I2C2_SCL
PB11.GPIO_Label=I2C2_SDA(OLED)
PB11.Signal=I2C2_SDA
PB13.Signal=TIM1_CH1N
PB3.GPIO_Label=nSCS
PB3.Signal=GPIO_Output
PB4.GPIO_Label=nFAULT
PB4.Signal=GPIO_Output
PB6.Signal=I2C1_SCL
PB7.Signal=I2C1_SDA
PB8.Signal=CAN1_RX
PB9.Signal=CAN1_TX
PC10.Signal=USART3_TX
PC11.Signal=USART3_RX
PC12.GPIO_Label=DRV8316_CS
PC12.Signal=GPIO_Output
PC2.GPIO_Label=SOC
PC2.Signal=ADCx_IN12
PC3.GPIO_Label=SOB
PC3.Signal=ADCx_IN13
PH0-OSC_IN.Signal=RCC_OSC_IN
PH1-OSC_OUT.Signal=RCC_OSC_OUT

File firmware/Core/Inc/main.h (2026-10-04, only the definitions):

#define SOC_Pin GPIO_PIN_2
#define SOC_GPIO_Port GPIOC
#define SOB_Pin GPIO_PIN_3
#define SOB_GPIO_Port GPIOC
#define SOA_Pin GPIO_PIN_0
#define SOA_GPIO_Port GPIOA
#define VIN_SENSE_Pin GPIO_PIN_1
#define VIN_SENSE_GPIO_Port GPIOA
#define GPIO_EXTI2_Pin GPIO_PIN_2
#define GPIO_EXTI2_GPIO_Port GPIOA
#define GPIO_EXTI3_Pin GPIO_PIN_3
#define GPIO_EXTI3_GPIO_Port GPIOA
#define SPI1_CS_Pin GPIO_PIN_4
#define SPI1_CS_GPIO_Port GPIOA
#define I2C2_SCL_Pin GPIO_PIN_10
#define I2C2_SCL_GPIO_Port GPIOB
#define I2C2_SDA_Pin GPIO_PIN_11
#define I2C2_SDA_GPIO_Port GPIOB
#define nSCS_Pin GPIO_PIN_3
#define nSCS_GPIO_Port GPIOB
#define DRV_OFF_Pin GPIO_PIN_4
#define DRV_OFF_GPIO_Port GPIOB

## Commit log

2026-10-04 Release V1.6
    [128x32 OLED.step, Amass_XT30PW-M_pcb solder.stp, Inductor_63.step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]
2026-10-08 V1.7 Release
    [MeowCU.kicad_pcb, MeowCU.kicad_sch, MeowCU.step]

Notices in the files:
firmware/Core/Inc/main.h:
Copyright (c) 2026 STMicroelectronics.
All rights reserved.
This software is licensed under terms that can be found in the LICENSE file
